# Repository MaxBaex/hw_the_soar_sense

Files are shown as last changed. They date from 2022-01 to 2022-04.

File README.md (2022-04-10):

# PCB design for sense module
Minimalistic very small temperature and humidity sensing device with CAN interface. Could also be used for other CAN bus attached sensing tasks. 

## Facts
- SWD interface
- STM32F103 48LQFP 8 MHz Crystal 
- CAN transceiver: MAX3051EKA+T 
- 5 to 16V power supply with 3.3V LDO: SPX3819M5-L-3-3/TR
- Temperature and Humidity sensing with SHT35-DIS-B or SHT31
- 4 analog inputs, SPI, 2 I2C and UART 
- Boot0 pin available for flashing via UART
- Pcb size 47.7mm x 23.2mm

## 3D Preview 
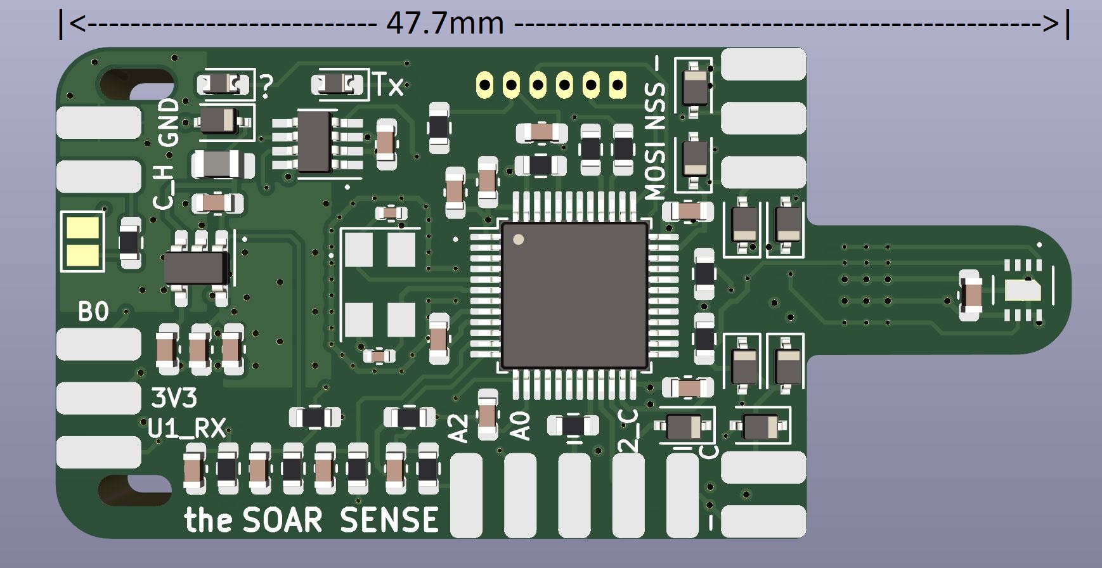
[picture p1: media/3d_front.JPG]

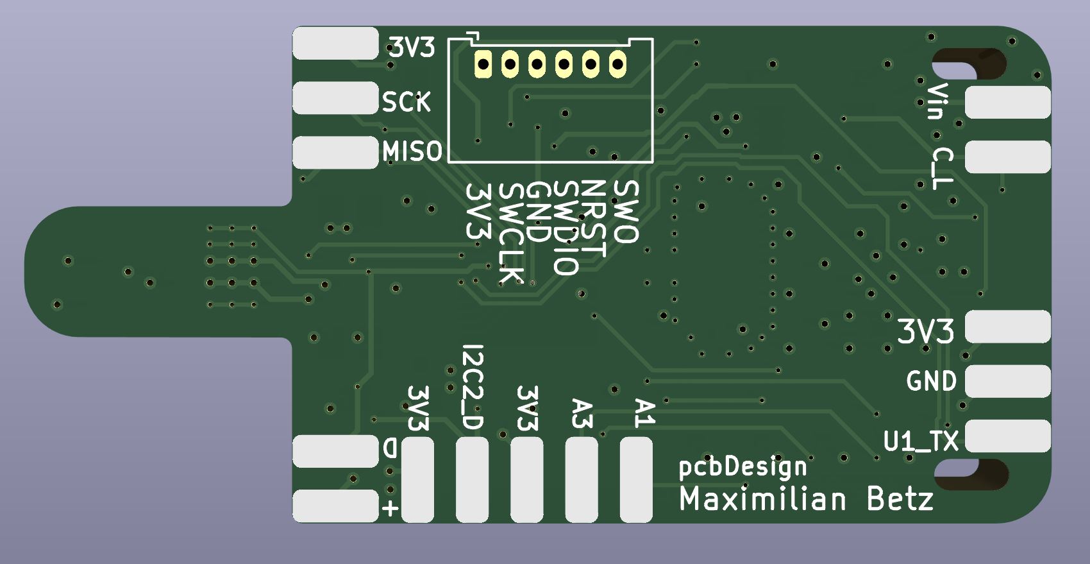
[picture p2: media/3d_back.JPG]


## TODO
- backside solder pads for differential pressure package 
- more backside connectors 
- review and feedback
- are the cable solder connections the right choice?
- make sensor voltage switchable! 
- add some signal leds

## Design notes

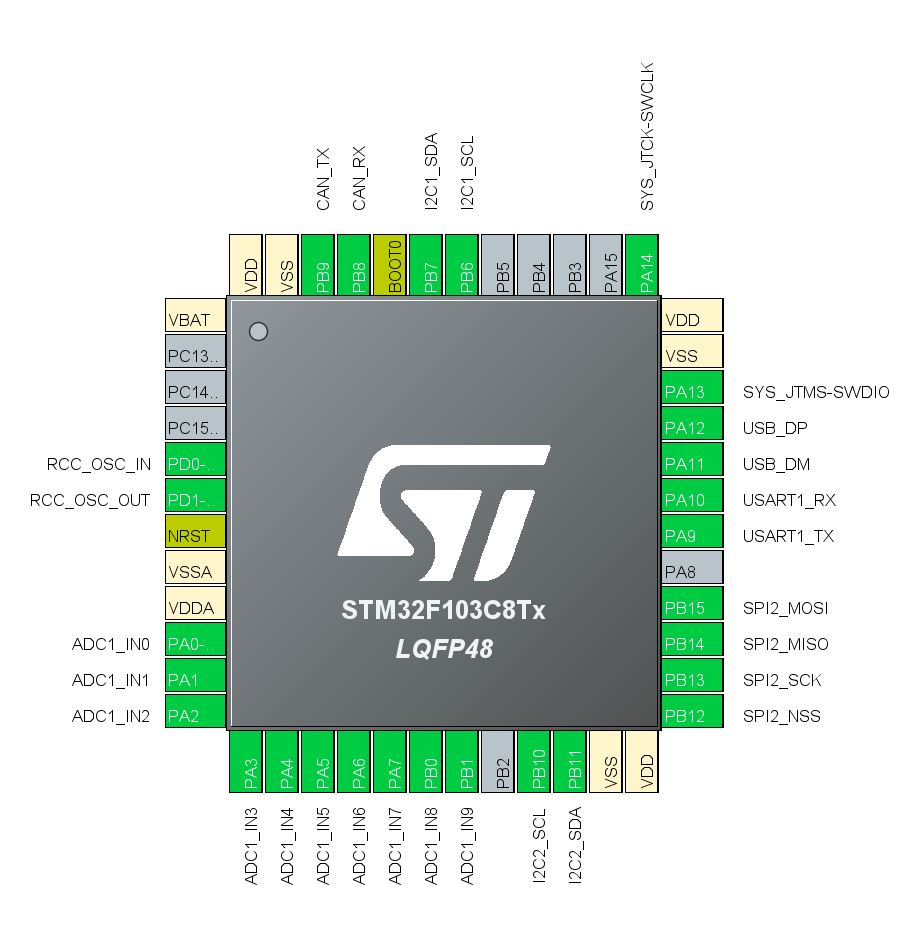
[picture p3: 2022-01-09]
media/pin_assignment.JPG

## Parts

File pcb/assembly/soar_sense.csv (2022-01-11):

Comment | Designator | Footprint | LCSC Part Number
10u | C1,C7 | Capacitor_SMD:C_0603_1608Metric | C91606
100n | C2,C6,C8,C9,C10,C11,C12,C13,C14,C15,C16,C17,C19 | Capacitor_SMD:C_0603_1608Metric | C14663
30p | C3,C5 | Capacitor_SMD:C_0402_1005Metric | C1570
10n | C4 | Capacitor_SMD:C_0603_1608Metric | C57112
LED_Small | D1,D2 | Diode_SMD:D_0603_1608Metric | C72041
D_Small | D3 | Diode_SMD:D_SOD-323 | C22624
D_TVS | D5,D6,D7,D8,D9,D10,D11,D12 | Diode_SMD:D_SOD-323 | C51450
FerriteBead_Small | FB1 | Inductor_SMD:L_0805_2012Metric | C1017
Conn_02x03_Top_Bottom | J1,J2,J7 | OWN_Parts:pcb_edge_2_3
Conn_02x02_Top_Bottom | J3,J4,J5 | OWN_Parts:pcb_edge_2_2
Conn_01x06 | J8 | Connector_Molex:Molex_PicoBlade_53048-0610_1x06_P1.25mm_Horizontal
SolderJumper_2_Open | JP1 | Jumper:SolderJumper-2_P1.3mm_Open_Pad1.0x1.5mm
10k | R1,R9,R10,R12,R13,R14,R15 | Resistor_SMD:R_0603_1608Metric | C25804
120R | R2 | Resistor_SMD:R_0603_1608Metric | C22787
4k7 | R5,R6 | Resistor_SMD:R_0603_1608Metric | C23162
R200 | R7,R8 | Resistor_SMD:R_0603_1608Metric | C8218
SPX3819M5-L-3-3 | U1 | Package_TO_SOT_SMD:SOT-23-5 | C9055
STM32F103CBTx | U2 | Package_QFP:LQFP-48_7x7mm_P0.5mm | C8304
SHT35-DIS | U3 | Sensor_Humidity:Sensirion_DFN-8-1EP_2.5x2.5mm_P0.5mm_EP1.1x1.7mm | C90161
MAX3051 | U4 | Package_TO_SOT_SMD:SOT-23-8_Handsoldering | C112005
8MHz | Y1 | Crystal:Crystal_SMD_5032-4Pin_5.0x3.2mm | C157341

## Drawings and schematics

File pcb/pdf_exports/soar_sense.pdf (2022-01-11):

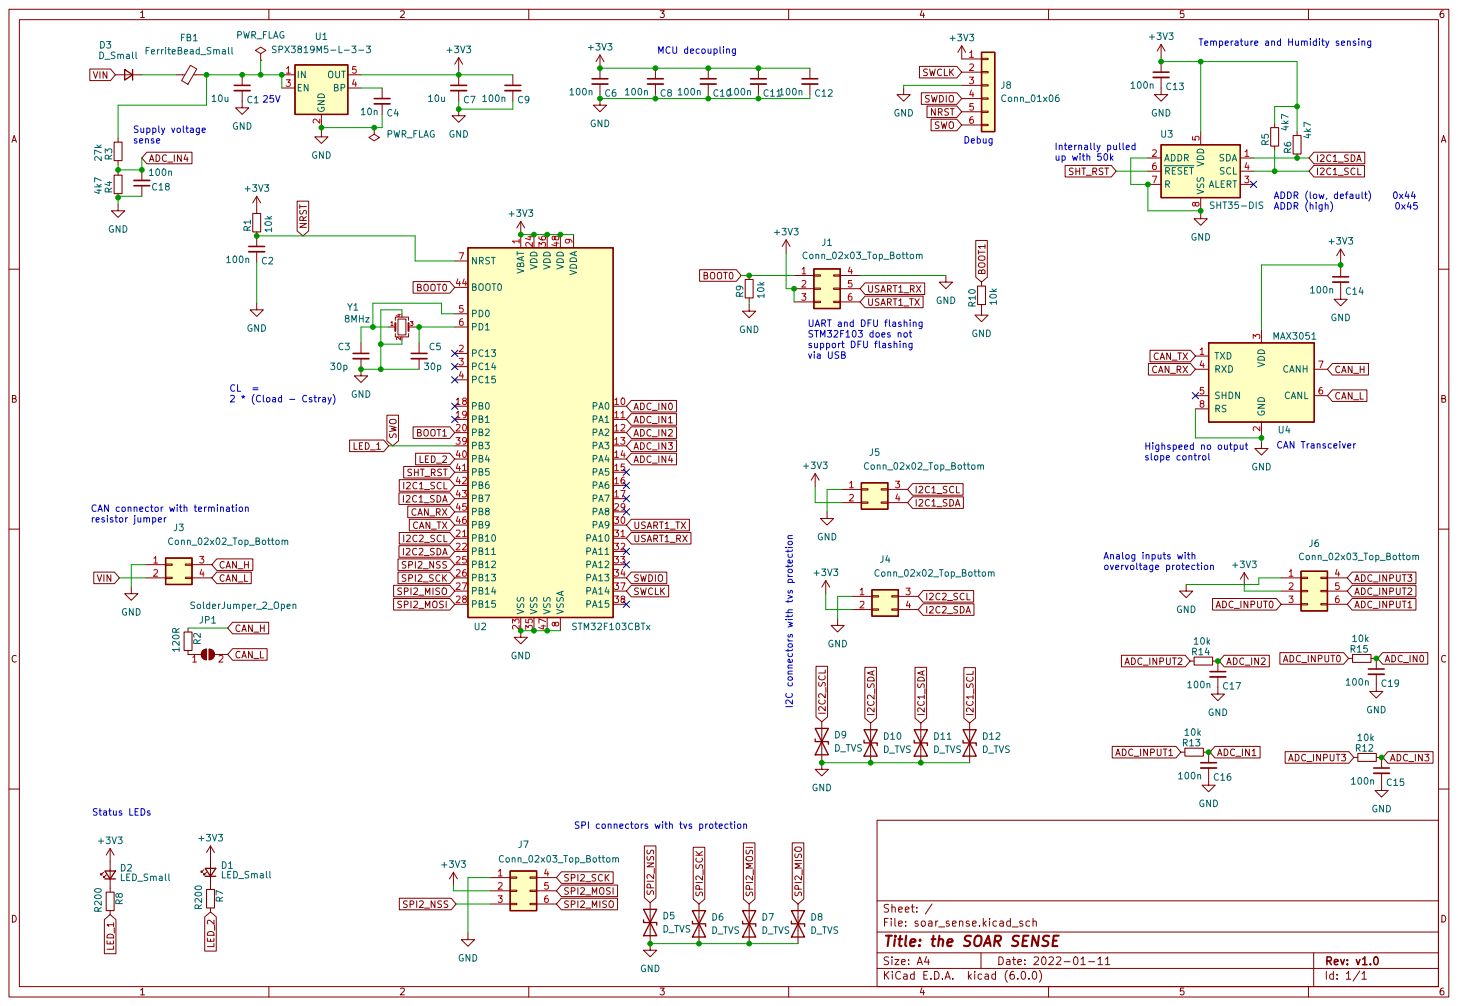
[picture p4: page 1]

1 PA0 10 PA1 11 PA2 12 PA3 13 PA4 14 PA5 15 PA6 16 PA7 17 PB0 18 PB1 19 PC13 2 PB2 20 PB10 21 PB11 22 VSS 23 VDD 24 PB12 25 PB13 26 PB14 27 PB15 28 PA8 29 PC14 3 PA9 30 PA10 31 PA11 32 PA12 33 PA13 34 VSS 35 VDD 36 PA14 37 PA15 38 PB3 39 PC15 4 PB4 40 PB5 41 PB6 42 PB7 43 BOOT0 44 PB8 45 PB9 46 VSS 47 VDD 48 PD0 5 PD1 6 NRST 7 VSSA

UART and DFU flashing STM32F103 does not support DFU flashing via USB

3 RXD 4 SHDN 5 CANL 6 CANH 7 RS 8 U4 MAX3051 GND

CAN connector with termination
resistor jumper

SPI connectors with tvs protection

File: soar_sense.kicad_sch Sheet: /
Id: 1/1 Title: the SOAR SENSE

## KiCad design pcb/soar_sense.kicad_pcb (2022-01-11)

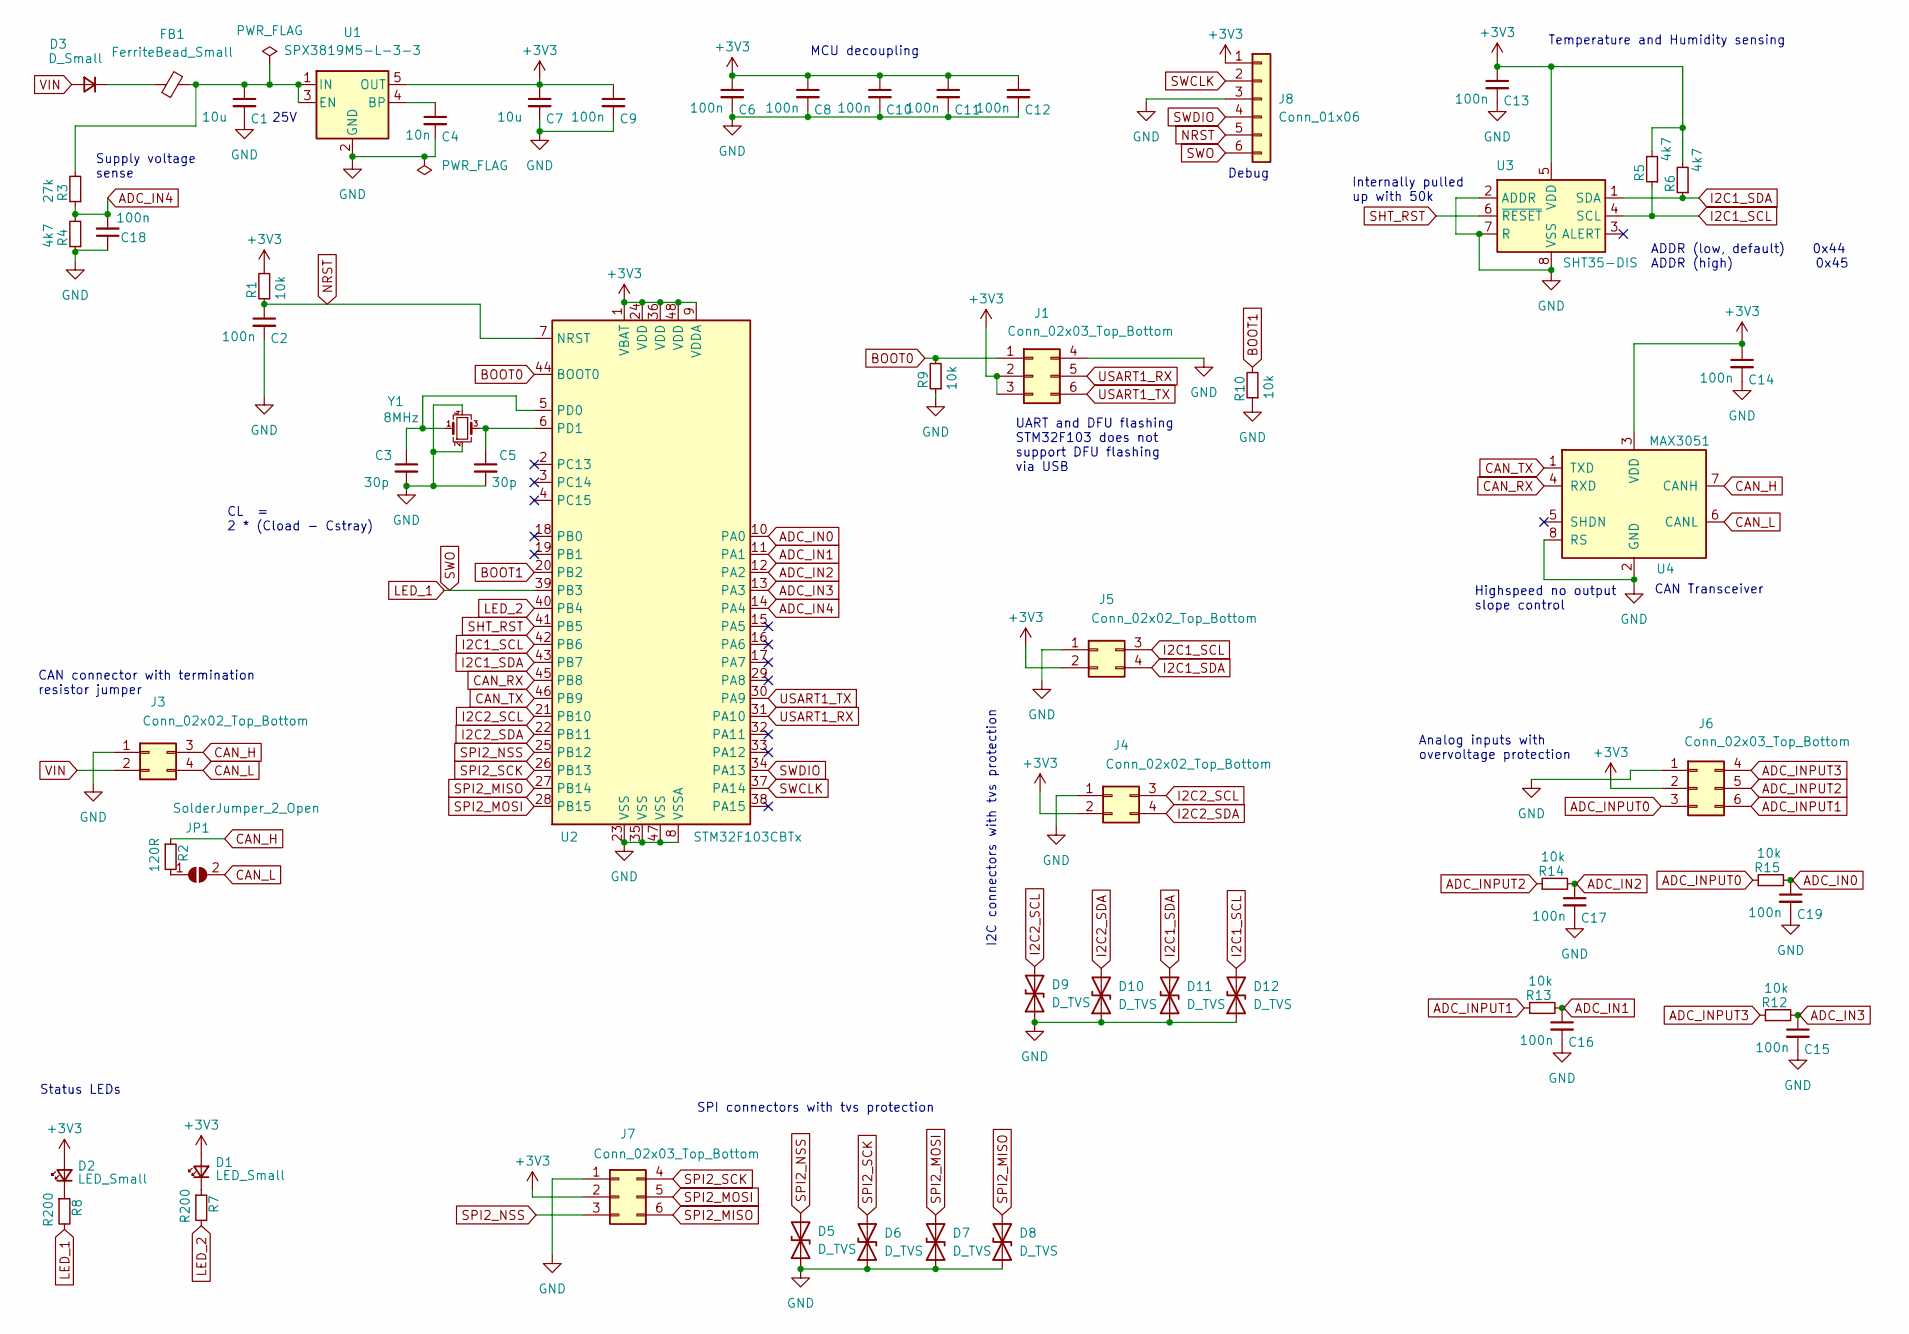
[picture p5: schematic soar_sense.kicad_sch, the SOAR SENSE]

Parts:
C1: 10u; C_0603_1608Metric; LCSC Part Number C91606
C2, C6, C8, C9, C10, C11, C12, C13, C14, C15, C16, C17, C18, C19: 100n; C_0603_1608Metric; LCSC Part Number C14663
C3, C5: 30p; C_0402_1005Metric; LCSC Part Number C1570
C4: 10n; C_0603_1608Metric; LCSC Part Number C57112
C7: 10u; C_0603_1608Metric; LCSC Part Number C19702
D1, D2: LED_Small; D_0603_1608Metric; LCSC Part Number C72041
D3: D_Small; D_SOD-323; LCSC Part Number C22624
D5, D6, D7, D8, D9, D10, D11, D12: D_TVS; D_SOD-323; LCSC Part Number C51450
FB1: FerriteBead_Small; L_0805_2012Metric; LCSC Part Number C1017
J1, J6, J7: Conn_02x03_Top_Bottom; pcb_edge_2_3
J3, J4, J5: Conn_02x02_Top_Bottom; pcb_edge_2_2
J8: Conn_01x06; Molex_PicoBlade_53048-0610_1x06_P1.25mm_Horizontal
JP1: SolderJumper_2_Open; SolderJumper-2_P1.3mm_Open_Pad1.0x1.5mm
R1, R9, R10, R12, R13, R14, R15: 10k; R_0603_1608Metric; LCSC Part Number C25804
R2: 120R; R_0603_1608Metric; LCSC Part Number C22787
R3: 27k; R_0603_1608Metric; LCSC Part Number C22967
R4, R5, R6: 4k7; R_0603_1608Metric; LCSC Part Number C23162
R7, R8: R200; R_0603_1608Metric; LCSC Part Number C8218
U1: SPX3819M5-L-3-3; SOT-23-5; LCSC Part Number C9055
U2: STM32F103CBTx; LQFP-48_7x7mm_P0.5mm; LCSC Part Number C8304
U3: SHT35-DIS; Sensirion_DFN-8-1EP_2.5x2.5mm_P0.5mm_EP1.1x1.7mm; LCSC Part Number C90161
U4: MAX3051; SOT-23-8_Handsoldering; LCSC Part Number C112005
Y1: 8MHz; Crystal_SMD_5032-4Pin_5.0x3.2mm; LCSC Part Number C157341

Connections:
+3V3: C6.1, C7.1, C8.1, C9.1, C10.1, C11.1, C12.1, C13.1, C14.1, D1.2 (A), D2.2 (A), J1.2, J1.3, J4.2, J5.2, J6.2, J7.2, J8.1, R1.2, R5.2, R6.2, U1.5 (OUT), U2.1 (VBAT), U2.9 (VDDA), U2.24 (VDD), U2.36 (VDD), U2.48 (VDD), U3.5 (VDD), U4.3 (VDD)
ADC_IN0: C19.1, R15.2, U2.10 (PA0)
ADC_IN1: C16.1, R13.2, U2.11 (PA1)
ADC_IN2: C17.1, R14.2, U2.12 (PA2)
ADC_IN3: C15.1, R12.2, U2.13 (PA3)
ADC_IN4: C18.2, R3.1, R4.2, U2.14 (PA4)
ADC_INPUT0: J6.3, R15.1
ADC_INPUT1: J6.6, R13.1
ADC_INPUT2: J6.5, R14.1
ADC_INPUT3: J6.4, R12.1
BOOT0: J1.1, R9.2, U2.44 (BOOT0)
BOOT1: R10.2, U2.20 (PB2)
CAN_H: J3.3, R2.1, U4.7 (CANH)
CAN_L: J3.4, JP1.2 (B), U4.6 (CANL)
CAN_RX: U2.45 (PB8), U4.4 (RXD)
CAN_TX: U2.46 (PB9), U4.1 (TXD)
GND: C1.2, C2.2, C3.2, C4.2, C5.2, C6.2, C7.2, C8.2, C9.2, C10.2, C11.2, C12.2, C13.2, C14.2, C15.2, C16.2, C17.2, C18.1, C19.2, D5.1 (A1), D6.1 (A1), D7.1 (A1), D8.1 (A1), D9.1 (A1), D10.1 (A1), D11.1 (A1), D12.1 (A1), J1.4, J3.1, J4.1, J5.1, J6.1, J7.1, J8.3, R4.1, R9.1, R10.1, U1.2 (GND), U2.8 (VSSA), U2.23 (VSS), U2.35 (VSS), U2.47 (VSS), U3.2 (ADDR), U3.7 (R), U3.8 (VSS), U3.9 (VSS), U4.2 (GND), U4.8 (RS), Y1.2, Y1.4
I2C1_SCL: D12.2 (A2), J5.3, R5.1, U2.42 (PB6), U3.4 (SCL)
I2C1_SDA: D11.2 (A2), J5.4, R6.1, U2.43 (PB7), U3.1 (SDA)
I2C2_SCL: D9.2 (A2), J4.3, U2.21 (PB10)
I2C2_SDA: D10.2 (A2), J4.4, U2.22 (PB11)
LED_1: J8.6, R8.2, U2.39 (PB3)
LED_2: R7.2, U2.40 (PB4)
NRST: C2.1, J8.5, R1.1, U2.7 (NRST)
unnamed: C1.1, FB1.2, R3.2, U1.1 (IN), U1.3 (EN)
unnamed: C3.1, U2.5 (PD0), Y1.1
unnamed: C4.1, U1.4 (BP)
unnamed: C5.1, U2.6 (PD1), Y1.3
unnamed: D1.1 (K), R7.1
unnamed: D2.1 (K), R8.1
unnamed: D3.1 (K), FB1.1
unnamed: JP1.1 (A), R2.2
SHT_RST: U2.41 (PB5), U3.6 (~RESET)
SPI2_MISO: D8.2 (A2), J7.6, U2.27 (PB14)
SPI2_MOSI: D7.2 (A2), J7.5, U2.28 (PB15)
SPI2_NSS: D5.2 (A2), J7.3, U2.25 (PB12)
SPI2_SCK: D6.2 (A2), J7.4, U2.26 (PB13)
SWCLK: J8.2, U2.37 (PA14)
SWDIO: J8.4, U2.34 (PA13)
USART1_RX: J1.5, U2.31 (PA10)
USART1_TX: J1.6, U2.30 (PA9)
VIN: D3.2 (A), J3.2

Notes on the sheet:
Supply voltage sense
MCU decoupling
CAN connector with termination resistor jumper
I2C connectors with tvs protection
25V
ADDR (low, default) 0x44 ADDR (high) 0x45
Temperature and Humidity sensing
Internally pulled up with 50k
CAN Transceiver
Analog inputs with overvoltage protection
Highspeed no output slope control
Debug
CL = 2 * (Cload - Cstray)
Status LEDs
UART and DFU flashing STM32F103 does not support DFU flashing via USB
SPI connectors with tvs protection

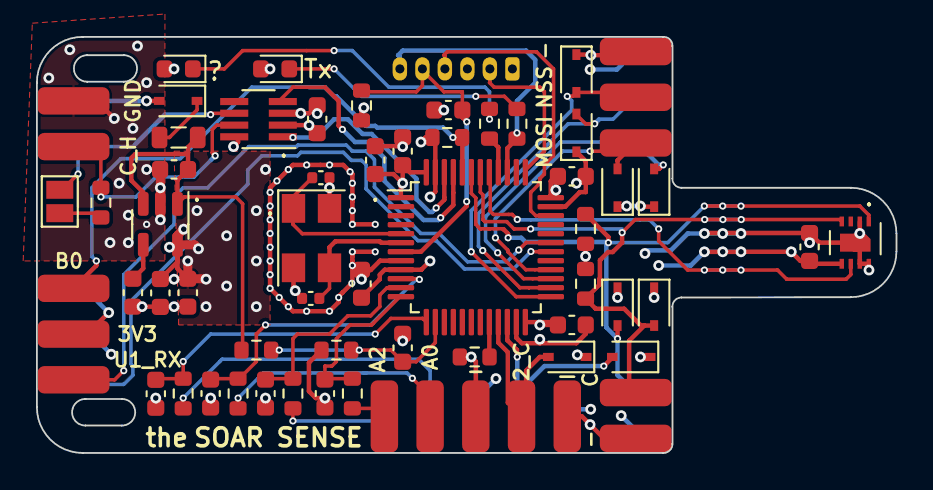
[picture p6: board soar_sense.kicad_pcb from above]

Board: 4 copper layers, 47.8 x 23.1 mm, 58 parts (1 on the bottom side), 42 nets.

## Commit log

2022-01-09 today done
    [soar_sense.kicad_pcb, soar_sense.kicad_sch]
2022-01-10 added crystal
    [soar_sense.kicad_pcb, soar_sense.kicad_sch]
2022-01-10 sht connected
    [soar_sense.kicad_pcb, soar_sense.kicad_sch]
2022-01-11 added copper heat cooling areas
    [soar_sense.kicad_pcb, soar_sense.kicad_sch]
2022-01-11 added supply voltage sensing
    [soar_sense.kicad_pcb, soar_sense.kicad_sch]
2022-01-11 added holes
    [soar_sense.kicad_pcb]
2022-01-11 updated documentation
    [soar_sense.csv, soar_sense.kicad_pcb, soar_sense.kicad_sch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]
